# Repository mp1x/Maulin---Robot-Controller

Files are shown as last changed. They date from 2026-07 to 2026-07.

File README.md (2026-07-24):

# Maulin---Robot-Controller
This project is a custom ESP32-based robotics controller designed for dual DC motors, quadrature encoders, an MPU6050 IMU, SSD1306 OLED display, emergency stop system, and battery monitoring. The project includes a full KiCad schematic, PCB layout, Wokwi simulation, and ESP32 firmware.

This project is not a robot itself, however, it is the electronics that power a robot, the complete control system that acts as the robot’s brain. Instead of building wheels or a chassis, this project focuses on designing a universal robotics controller built around the ESP32, capable of driving motors, reading quadrature encoders, processing IMU data, handling emergency stop safety, monitoring battery voltage, and displaying system information on an OLED dashboard. The controller integrates all the core functions real robots rely on internally: motion tracking, speed and distance measurement, drift correction, orientation sensing, and safety logic. This board can be mounted onto any future robot—rovers, line followers, balancing robots, robotic arms, or any system that needs precise motor control and feedback. In short, this project builds the brain, not the body, forming a professional foundation for future robotics development.

## Wokwi Simulation
This project includes a full Wokwi simulation of the ESP32, OLED, IMU, and encoders.

Simulation link: https://wokwi.com/projects/468589263635231745

## Project Files
- /schematic — KiCad schematic + PNG/PDF
- /pcb — PCB layout screenshots + 3D view
- /firmware — ESP32 code
- /wokwi — Simulation files

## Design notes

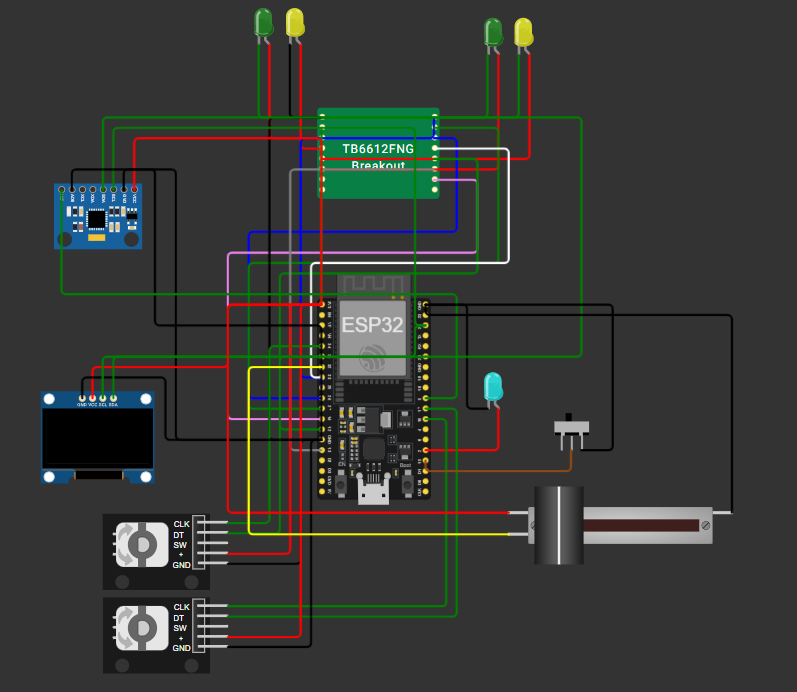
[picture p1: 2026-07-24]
wokwi/wokwi.png

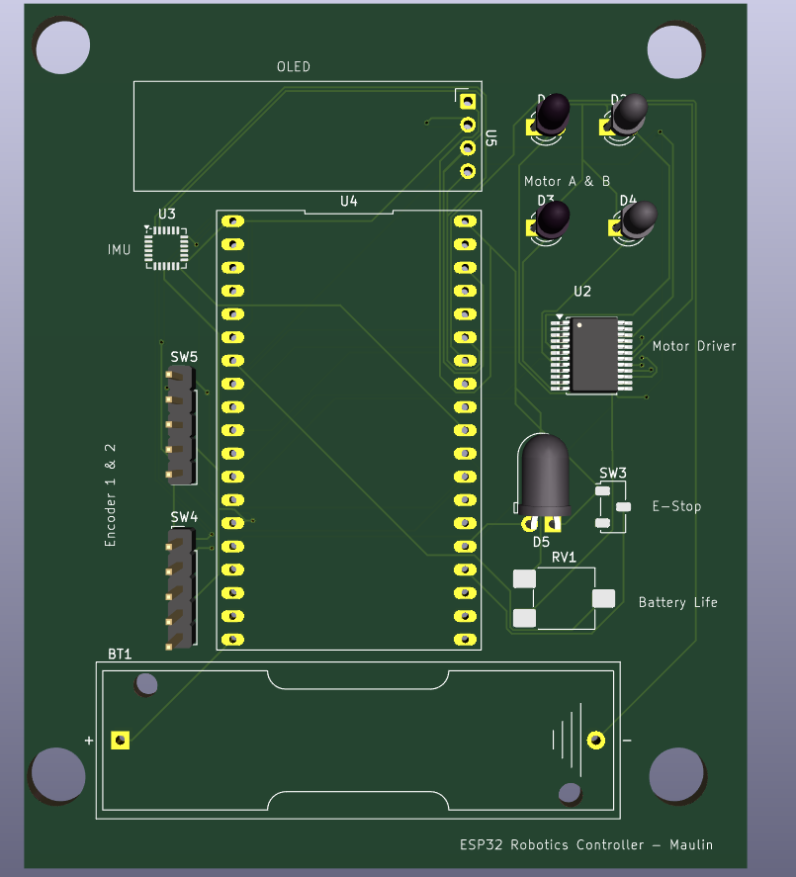
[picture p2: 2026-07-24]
pcb/PCB_roboticscontroller_3D_maulin.png

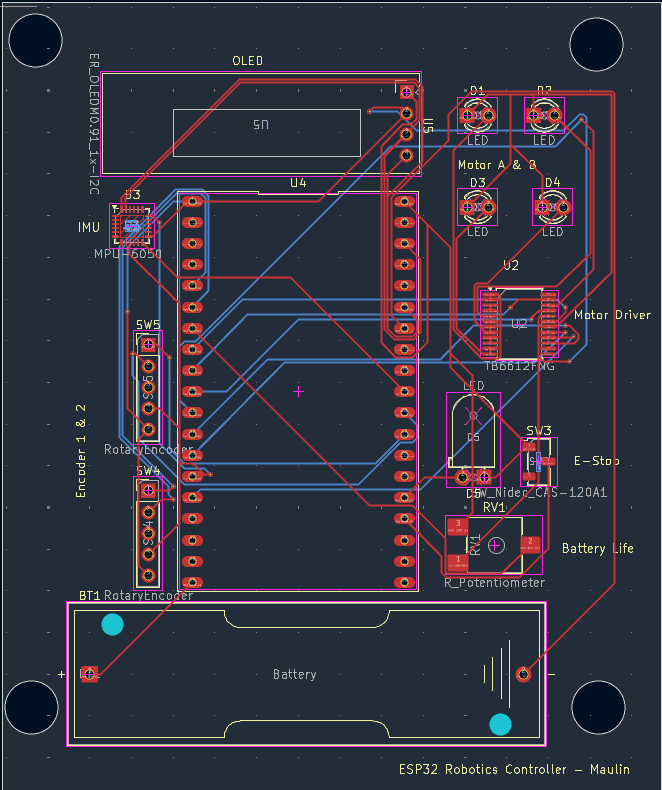
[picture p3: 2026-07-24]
pcb/PCB_roboticscontroller_maulin.png

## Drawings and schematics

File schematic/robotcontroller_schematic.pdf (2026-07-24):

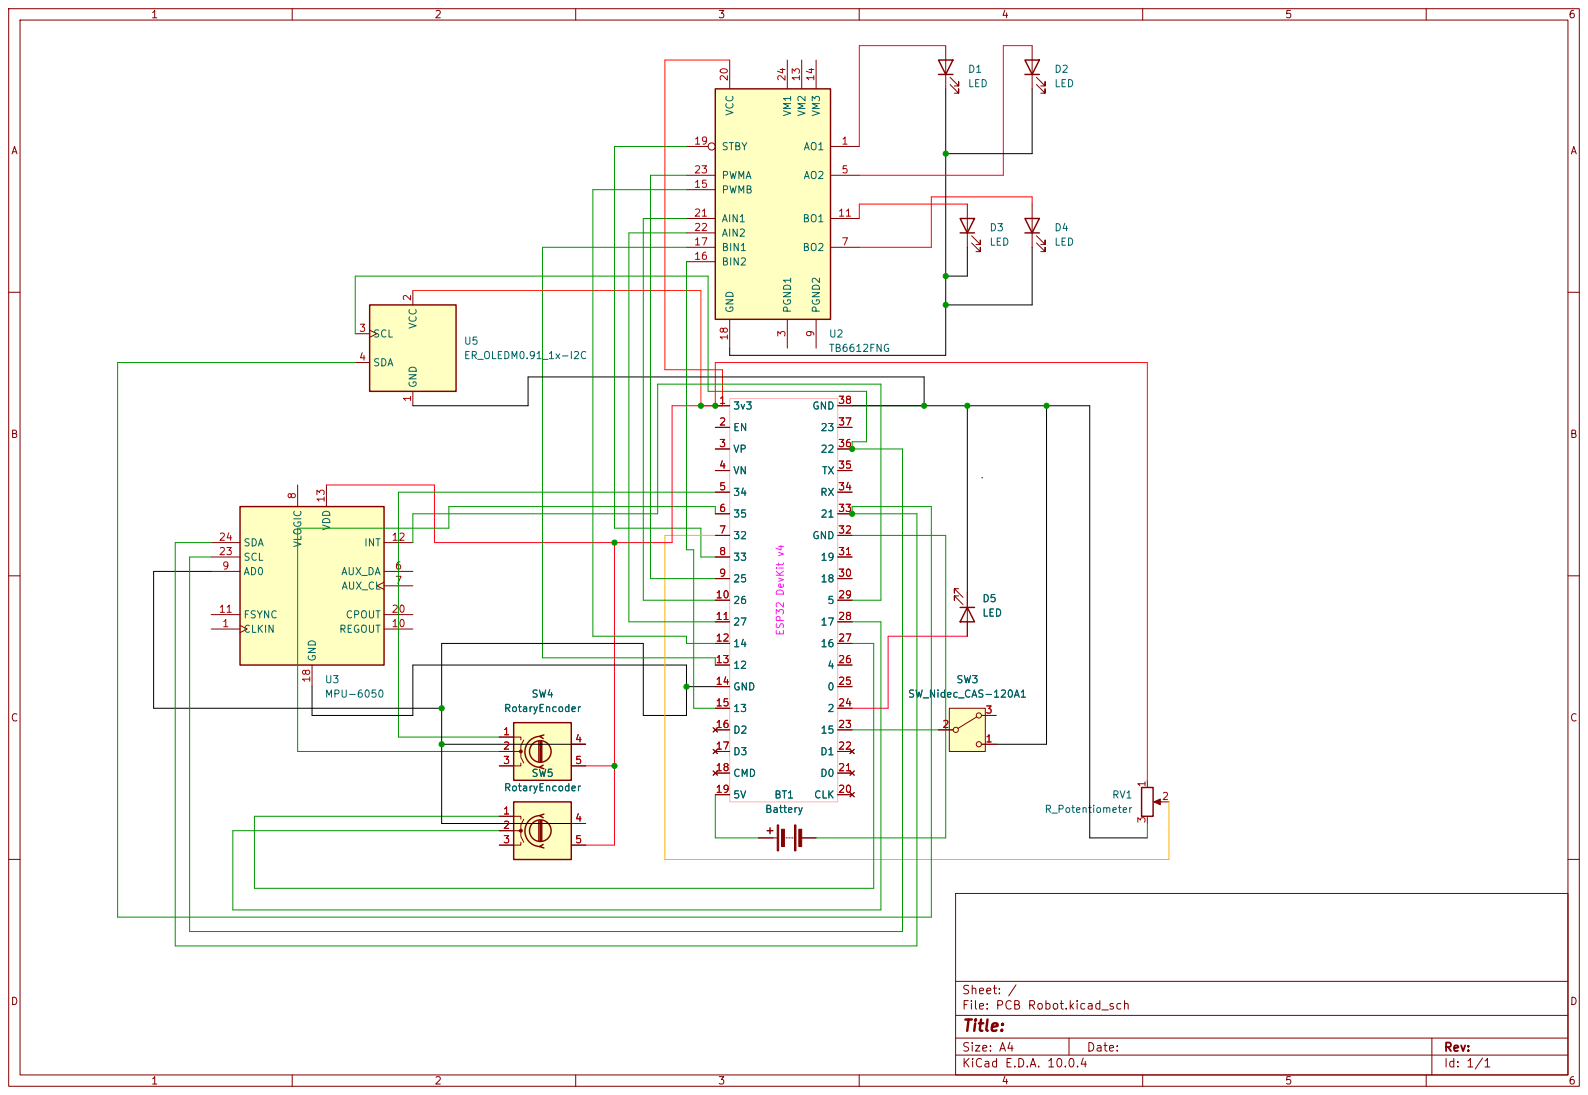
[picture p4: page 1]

19 31 GND 32 19 31 GND 32 33 8 33 8 18 30 18 30 | 29 29

Size: A4 | Rev:
KiCad E.D.A. 10.0.4 | Id: 1/1

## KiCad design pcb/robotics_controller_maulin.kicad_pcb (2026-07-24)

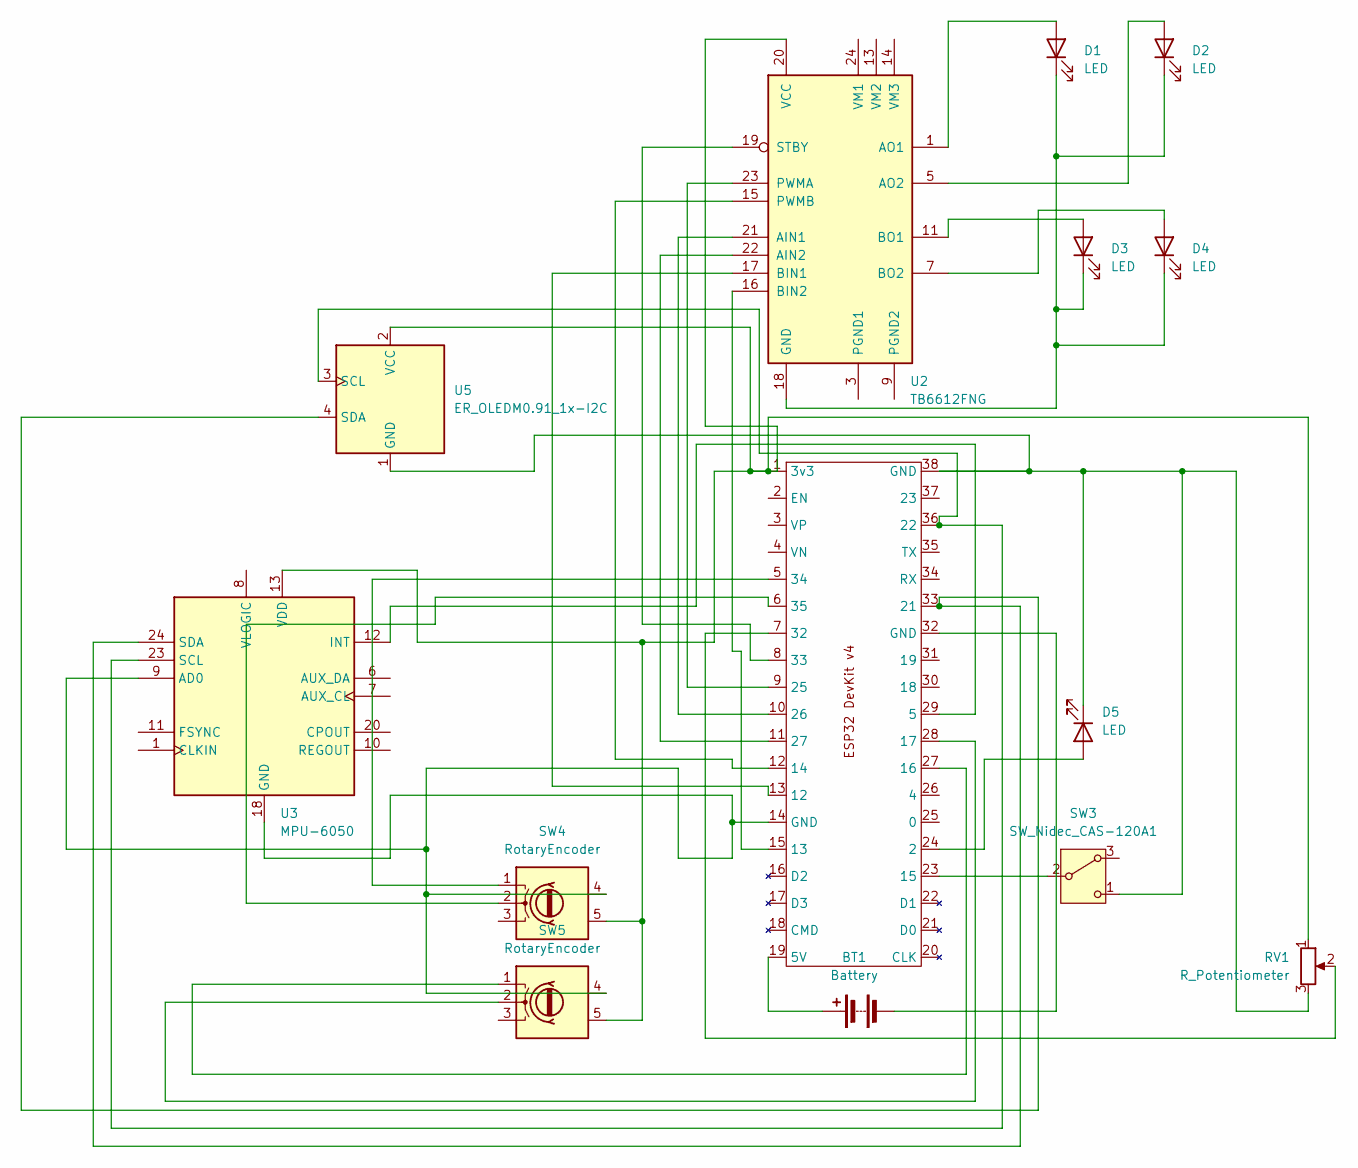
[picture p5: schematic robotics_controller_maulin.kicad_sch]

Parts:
BT1: Battery; BatteryHolder_Keystone_2460_1xAA
D1, D3: LED; LED_D3.0mm_IRBlack
D2, D4: LED; LED_D3.0mm_IRGrey
D5: LED; LED_D5.0mm_Horizontal_O1.27mm_Z3.0mm_IRGrey
RV1: R_Potentiometer; Potentiometer_ACP_CA6-VSMD_Vertical
SW3: SW_Nidec_CAS-120A1; Nidec_Copal_CAS-120A
SW4, SW5: RotaryEncoder; PinHeader_1x05_P2.54mm_Vertical
U2: TB6612FNG; SSOP-24_5.3x8.2mm_P0.65mm
U3: MPU-6050; InvenSense_QFN-24_4x4mm_P0.5mm
U4: ESP32-DevKitC-V4-b
U5: ER_OLEDM0.91_1x-I2C

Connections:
unnamed: BT1.1 (+), U4.19 (5V)
unnamed: BT1.2 (-), U4.32 (GND)
unnamed: D1.2 (A), U2.1 (AO1), U2.2 (AO1)
unnamed: D1.1 (K), D2.1 (K), D3.1 (K), D4.1 (K), U2.18 (GND)
unnamed: D2.2 (A), U2.5 (AO2), U2.6 (AO2)
unnamed: D3.2 (A), U2.11 (BO1), U2.12 (BO1)
unnamed: D4.2 (A), U2.7 (BO2), U2.8 (BO2)
unnamed: D5.2 (A), U4.24 (2)
unnamed: D5.1 (K), RV1.3, SW3.1 (C), U4.38 (GND), U5.1 (GND)
unnamed: SW3.2 (B), U4.23 (15)
unnamed: SW4.1 (CLK), U4.5 (34)
unnamed: SW4.2 (DT), U4.6 (35)
unnamed: SW4.4 (GND), SW5.4 (GND), U3.9 (AD0), U3.18 (GND), U4.14 (GND)
unnamed: RV1.1, SW4.5 (VCC), SW5.5 (VCC), U2.20 (VCC), U3.13 (VDD), U4.1 (3v3), U5.2 (VCC)
unnamed: SW5.1 (CLK), U4.27 (16)
unnamed: SW5.2 (DT), U4.28 (17)
unnamed: U2.21 (AIN1), U4.10 (26)
unnamed: U2.22 (AIN2), U4.11 (27)
unnamed: U2.17 (BIN1), U4.13 (12)
unnamed: U2.16 (BIN2), U4.15 (13)
unnamed: U2.3 (PGND1), U2.4 (PGND1)
unnamed: U2.9 (PGND2), U2.10 (PGND2)
unnamed: U2.23 (PWMA), U4.9 (25)
unnamed: U2.15 (PWMB), U4.12 (14)
unnamed: U2.19 (STBY), U4.8 (33)
unnamed: U3.12 (INT), U4.29 (5)
unnamed: U3.23 (SCL), U4.36 (22), U5.3 (SCL)
unnamed: U3.24 (SDA), U4.33 (21), U5.4 (SDA)
unnamed: RV1.2, U4.7 (32)

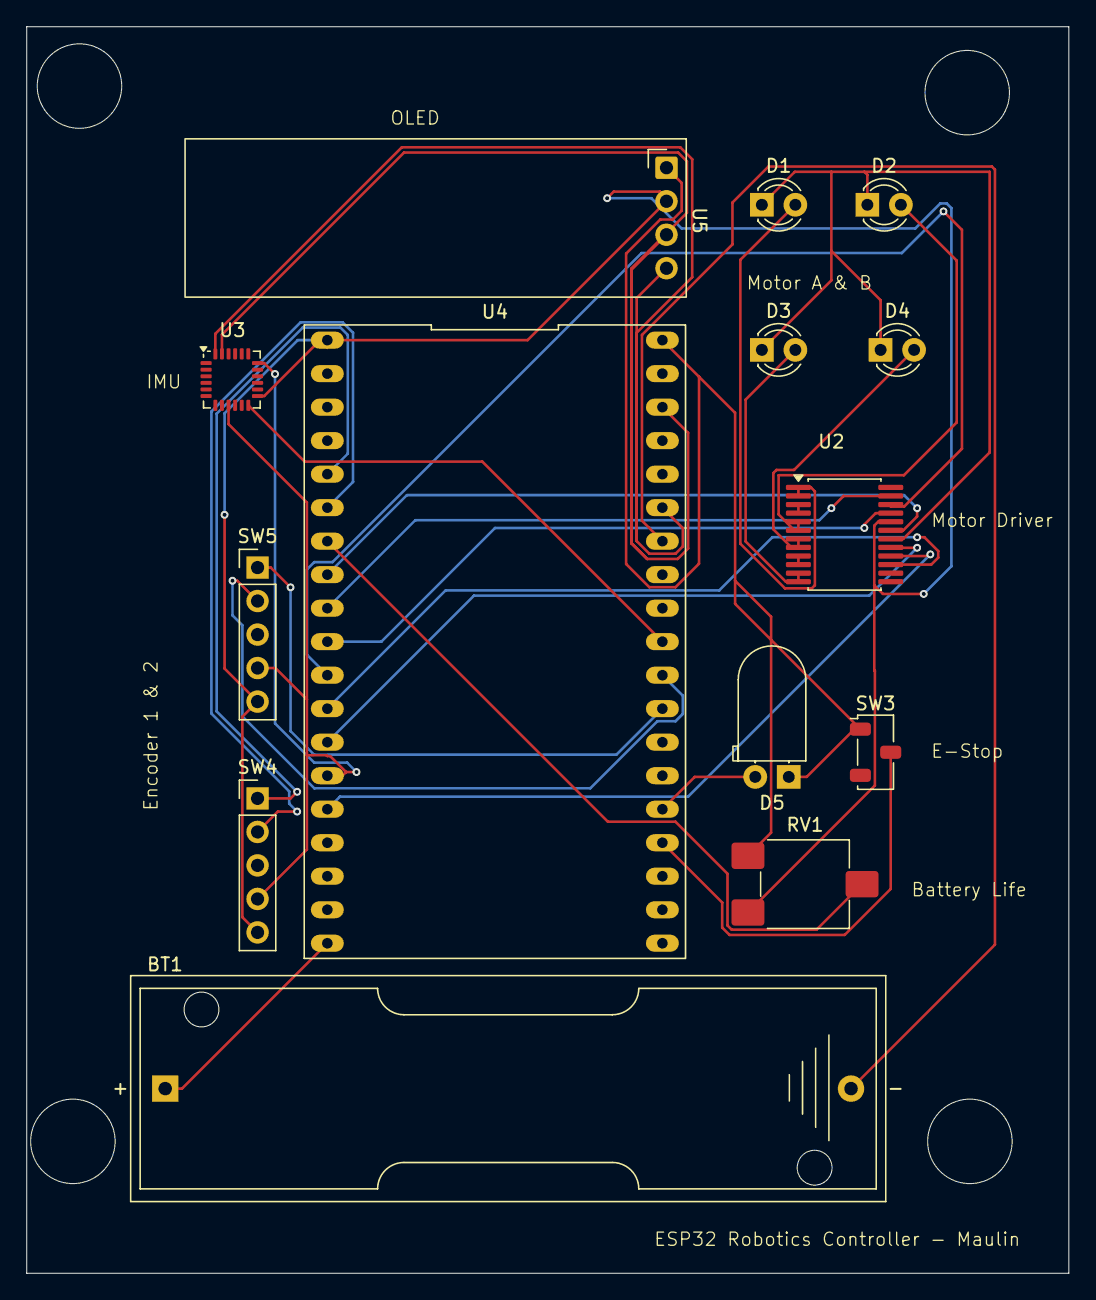
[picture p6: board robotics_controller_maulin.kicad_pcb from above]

Board: 2 copper layers, 79.0 x 94.5 mm, 14 parts (0 on the bottom side), 29 nets.

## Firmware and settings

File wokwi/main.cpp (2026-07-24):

#include <Arduino.h>
#include <Wire.h>
#include <Adafruit_MPU6050.h>
#include <Adafruit_Sensor.h>
#include <Adafruit_GFX.h>
#include <Adafruit_SSD1306.h>

// =========================
// OLED DISPLAY
// =========================
#define SCREEN_WIDTH 128
#define SCREEN_HEIGHT 64
Adafruit_SSD1306 display(SCREEN_WIDTH, SCREEN_HEIGHT, &Wire, -1);

// =========================
// MOTOR DRIVER PINS
// =========================
#define PWMA 25
#define AIN1 26
#define AIN2 27

#define PWMB 14
#define BIN1 12
#define BIN2 13

#define STBY 33

// =========================
// EMERGENCY STOP
// =========================
#define ESTOP_BTN 15
#define ESTOP_LED 2

// =========================
// ENCODERS
// =========================
#define ENC1_CLK 34
#define ENC1_DT  35

#define ENC2_CLK 16
#define ENC2_DT  17

// =========================
// IMU (MPU6050)
// =========================
Adafruit_MPU6050 mpu;
float lastGyroZ = 0;

// =========================
// BATTERY MONITOR (ADC)
// =========================
#define BATTERY_PIN 32
float batteryVoltage = 0;
float batteryPercent = 0;

// =========================
// STATE VARIABLES
// =========================
bool estop_active = false;
bool estop_released_wait = false;
unsigned long estop_release_time = 0;

// =========================
// ENCODER COUNTS
// =========================
volatile long encoderA_count = 0;
volatile long encoderB_count = 0;

// =========================
// ENCODER INTERRUPTS
// =========================
void IRAM_ATTR encoderA_ISR() {
  int clk = digitalRead(ENC1_CLK);
  int dt  = digitalRead(ENC1_DT);
  if (clk == dt) encoderA_count++;
  else encoderA_count--;
}

void IRAM_ATTR encoderB_ISR() {
  int clk = digitalRead(ENC2_CLK);
  int dt  = digitalRead(ENC2_DT);
  if (clk == dt) encoderB_count++;
  else encoderB_count--;
}

// =========================
// DISTANCE CALCULATION
// =========================
float cm_per_step = 1.02;

float getDistanceA() { return encoderA_count * cm_per_step; }
float getDistanceB() { return encoderB_count * cm_per_step; }

// =========================
// SPEED CALCULATION
// =========================
unsigned long lastSpeedTime = 0;
long lastA = 0;
long lastB = 0;

float speedA = 0;
float speedB = 0;

void updateSpeed() {
  unsigned long now = millis();
  if (now - lastSpeedTime >= 1000) {
    speedA = (encoderA_count - lastA) * cm_per_step;
    speedB = (encoderB_count - lastB) * cm_per_step;
    lastA = encoderA_count;
    lastB = encoderB_count;
    lastSpeedTime = now;
  }
}

// =========================
// IMU READ FUNCTION
// =========================
void readIMU() {
  sensors_event_t a, g, temp;
  mpu.getEvent(&a, &g, &temp);
  lastGyroZ = g.gyro.z;
}

// =========================
// BATTERY MONITOR FUNCTION
// =========================
void updateBattery() {
  int raw = analogRead(BATTERY_PIN);      // 0–4095
  float volts = (raw / 4095.0) * 3.3;     // Convert to 0–3.3V
  batteryVoltage = volts;

  batteryPercent = (batteryVoltage / 3.3) * 100.0;
  if (batteryPercent > 100) batteryPercent = 100;
  if (batteryPercent < 0) batteryPercent = 0;
}

// =========================
// SERIAL TELEMETRY (prints once per second)
// =========================
unsigned long lastPrint = 0;
unsigned long lastBatteryPrint = 0;

void printTelemetry() {
  Serial.print("Dist L: ");
  Serial.print(getDistanceA());
  Serial.print("  Dist R: ");
  Serial.println(getDistanceB());

  Serial.print("Speed L: ");
  Serial.print(speedA);
  Serial.print("  Speed R: ");
  Serial.println(speedB);

  Serial.print("Gyro Z: ");
  Serial.println(lastGyroZ);

  Serial.println("----------------------");
}

void printBatteryEvery5Sec() {
  if (millis() - lastBatteryPrint >= 5000) {
    Serial.print("Battery Voltage: ");
    Serial.print(batteryVoltage, 2);
    Serial.print(" V  (");
    Serial.print(batteryPercent, 0);
    Serial.println("%)");
    lastBatteryPrint = millis();
  }
}

// =========================
// OLED DASHBOARD
// =========================
void updateOLED() {
  display.clearDisplay();
  display.setTextSize(1);
  display.setTextColor(SSD1306_WHITE);

  display.setCursor(0, 0);
  display.print("Dist L: ");
  display.print(getDistanceA());

  display.setCursor(0, 10);
  display.print("Dist R: ");
  display.print(getDistanceB());

  display.setCursor(0, 20);
  display.print("Speed L: ");
  display.print(speedA);

  display.setCursor(0, 30);
  display.print("Speed R: ");
  display.print(speedB);

  display.setCursor(0, 40);
  display.print("Gyro Z: ");
  display.print(lastGyroZ);

  display.setCursor(70, 0);
  display.print("Bat:");
  display.print(batteryVoltage, 2);

  display.setCursor(70, 10);
  display.print("Pct:");
  display.print(batteryPercent, 0);
  display.print("%");

  display.setCursor(0, 50);
  if (estop_active) display.print("ESTOP: ACTIVE");
  else display.print("ESTOP: OK");

  display.display();
}

// =========================
// MOTOR FUNCTIONS
// =========================
void motorA_forward(int speed) {
  digitalWrite(AIN1, HIGH);
  digitalWrite(AIN2, LOW);
  analogWrite(PWMA, speed);
}

void motorA_reverse(int speed) {
  digitalWrite(AIN1, LOW);
  digitalWrite(AIN2, HIGH);
  analogWrite(PWMA, speed);
}

void motorA_stop() {
  digitalWrite(AIN1, LOW);
  digitalWrite(AIN2, LOW);
  analogWrite(PWMA, 0);
}

void motorB_forward(int speed) {
  digitalWrite(BIN1, HIGH);
  digitalWrite(BIN2, LOW);
  analogWrite(PWMB, speed);
}

void motorB_reverse(int speed) {
  digitalWrite(BIN1, LOW);
  digitalWrite(BIN2, HIGH);
  analogWrite(PWMB, speed);
}

void motorB_stop() {
  digitalWrite(BIN1, LOW);
  digitalWrite(BIN2, LOW);
  analogWrite(PWMB, 0);
}

void stop_all() {
  motorA_stop();
  motorB_stop();
}

// =========================
// EMERGENCY STOP
// =========================
void checkEmergencyStop() {
  bool pressed = (digitalRead(ESTOP_BTN) == LOW);

  if (pressed && !estop_active) {
    estop_active = true;
    estop_released_wait = false;
    digitalWrite(ESTOP_LED, HIGH);
    stop_all();
    Serial.println("ESTOP ACTIVATED");
  }

  if (!pressed && estop_active) {
    estop_active = false;
    estop_released_wait = true;
    estop_release_time = millis();
    digitalWrite(ESTOP_LED, LOW);
    Serial.println("ESTOP RELEASED - WAITING 5 SEC");
    stop_all();
  }
}

// =========================
// STRAIGHT-LINE CORRECTION
// =========================
void correctStraight(int baseSpeed) {
  int diff = encoderA_count - encoderB_count;
  int correction = diff * 2;
  motorA_forward(baseSpeed - correction);
  motorB_forward(baseSpeed + correction);
}

// =========================
// SETUP
// =========================
void setup() {
  Serial.begin(115200);

  pinMode(PWMA, OUTPUT);
  pinMode(AIN1, OUTPUT);
  pinMode(AIN2, OUTPUT);

  pinMode(PWMB, OUTPUT);
  pinMode(BIN1, OUTPUT);
  pinMode(BIN2, OUTPUT);

  pinMode(STBY, OUTPUT);
  digitalWrite(STBY, HIGH);

  pinMode(ESTOP_BTN, INPUT_PULLUP);
  pinMode(ESTOP_LED, OUTPUT);

  pinMode(ENC1_CLK, INPUT);
  pinMode(ENC1_DT, INPUT);
  pinMode(ENC2_CLK, INPUT);
  pinMode(ENC2_DT, INPUT);

  attachInterrupt(ENC1_CLK, encoderA_ISR, CHANGE);
  attachInterrupt(ENC2_CLK, encoderB_ISR, CHANGE);

  Wire.begin(21, 22);

  if (!mpu.begin()) {
    Serial.println("Failed to find MPU6050!");
    while (1) delay(10);
  }

  mpu.setAccelerometerRange(MPU6050_RANGE_4_G);
  mpu.setGyroRange(MPU6050_RANGE_500_DEG);
  mpu.setFilterBandwidth(MPU6050_BAND_21_HZ);

  pinMode(BATTERY_PIN, INPUT);
  analogReadResolution(12);

  if (!display.begin(SSD1306_SWITCHCAPVCC, 0x3C)) {
    Serial.println("OLED not found!");
    while (true);
  }

  display.clearDisplay();
  display.setTextSize(1);
  display.setTextColor(SSD1306_WHITE);
  display.setCursor(0, 0);
  display.println("Controller Ready");
  display.display();

  Serial.println("Motor Controller + Encoders + IMU + OLED + Battery Ready");
}

// =========================
// LOOP
// =========================
void loop() {

  checkEmergencyStop();
  if (estop_active) { stop_all(); return; }

  if (estop_released_wait) {
    stop_all();
    if (millis() - estop_release_time >= 5000) {
      estop_released_wait = false;
    } else return;
  }

  // FORWARD
  Serial.println("FORWARD");
  correctStraight(180);
  delay(2000);

  updateSpeed();
  readIMU();
  updateBattery();
  printTelemetry();
  printBatteryEvery5Sec();
  updateOLED();

  checkEmergencyStop();
  if (estop_active) return;

  // REVERSE
  Serial.println("REVERSE");
  motorA_reverse(180);
  motorB_reverse(180);
  delay(2000);

  updateSpeed();
  readIMU();
  updateBattery();
  printTelemetry();
  printBatteryEvery5Sec();
  updateOLED();

  checkEmergencyStop();
  if (estop_active) return;

  // STOP
  Serial.println("STOP");
  stop_all();
  delay(1500);

  updateBattery();
  printBatteryEvery5Sec();
  updateOLED();
}

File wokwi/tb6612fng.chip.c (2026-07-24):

// Modified from code found in https://wokwi.com/projects/351764383409373773
// Modified to be digital, not analog, and 
// add pins for a TB6612FNG https://www.pololu.com/product/713

// See also L298N: https://wokwi.com/projects/410302035690579969
// and L298N: https://wokwi.com/projects/386822856593519617
// This progect TB6612FNG https://wokwi.com/projects/410323062531374081

/*
{
  "name": "TB6612FNG",
  "author": "David Forrest",
  "pins": [
    "GND",
    "VCC",
    "AO1",     
    "AO2",
    "BO2",
    "BO1",
    "VMOT",
    "GND",
    "GND",
    "PWMB",
    "BIN2",
    "BIN1",
    "nSTBY",
    "AIN1",
    "AIN2",
    "PWMA"
  ],
  "controls": [
    {
      "id": "Vs",
      "label": "External Voltage (V)",
      "type": "range",
      "min": 0,
      "max": 13.5,
      "step": 0.1
    }
  ]
}
*/

#include "wokwi-api.h"
#include <stdio.h>
#include <stdlib.h>

typedef struct {
  pin_t pin_AO1;
  pin_t pin_AO2;
  pin_t pin_BO1;
  pin_t pin_BO2;
  pin_t pin_AIN1;
  pin_t pin_AIN2;
  pin_t pin_BIN1;
  pin_t pin_BIN2;
  pin_t pin_nSTBY;
  pin_t pin_PWMA;
  pin_t pin_PWMB;
  uint32_t Vs_attr; 
} chip_state_t;



static void chip_pin_change(void *user_data, pin_t pin, uint32_t value);

void chip_init(void) {
  chip_state_t *chip = malloc(sizeof(chip_state_t));

  chip->pin_nSTBY = pin_init("nSTBY",INPUT_PULLDOWN);
  chip->pin_PWMA = pin_init("PWMA",INPUT);
  chip->pin_PWMB = pin_init("PWMB",INPUT);
  chip->pin_AIN1 = pin_init("AIN1",INPUT);
  chip->pin_AIN2 = pin_init("AIN2",INPUT);
  chip->pin_BIN1 = pin_init("BIN1",INPUT);
  chip->pin_BIN2 = pin_init("BIN2",INPUT);
  chip->pin_AO1 = pin_init("AO1",OUTPUT);
  chip->pin_AO2 = pin_init("AO2",OUTPUT);
  chip->pin_BO1 = pin_init("BO1",OUTPUT);
  chip->pin_BO2 = pin_init("BO2",OUTPUT);
  chip->Vs_attr = attr_init_float("Vs", 12.0);
  const pin_watch_config_t watch_config = {
    .edge = BOTH,
    .pin_change = chip_pin_change,
    .user_data = chip
  };
  pin_watch(chip->pin_PWMA, &watch_config);
  pin_watch(chip->pin_PWMB, &watch_config);
  pin_watch(chip->pin_AIN1, &watch_config);
  pin_watch(chip->pin_AIN2, &watch_config);
  pin_watch(chip->pin_BIN1, &watch_config);
  pin_watch(chip->pin_BIN2, &watch_config);
  pin_watch(chip->pin_nSTBY, &watch_config);
}

void chip_pin_change(void *user_data, pin_t pin, uint32_t value) {
  chip_state_t *chip = (chip_state_t*)user_data;
  int PWMA = pin_read(chip->pin_PWMA);
  int PWMB = pin_read(chip->pin_PWMB);
  int AIN1 = pin_read(chip->pin_AIN1);
  int AIN2 = pin_read(chip->pin_AIN2);
  int BIN1 = pin_read(chip->pin_BIN1);
  int BIN2 = pin_read(chip->pin_BIN2);
  int nSTBY = pin_read(chip->pin_nSTBY);
  float Vs = attr_read_float(chip->Vs_attr);
  
  // motor A control
  if (AIN1 && nSTBY) 
   // pin_dac_write(chip->pin_out1,PWMA*Vs);
    pin_write(chip->pin_AO1,PWMA);
  else
    pin_write(chip->pin_AO1,0);
  if (AIN2 && nSTBY)
    pin_write(chip->pin_AO2,PWMA);
  else
    pin_write(chip->pin_AO2,0);
  //motor B control
  if (BIN1 && nSTBY) 
    pin_write(chip->pin_BO1,PWMB);
  else
    pin_write(chip->pin_BO1,0);
  if (BIN2 && nSTBY)
    pin_write(chip->pin_BO2,PWMB);
  else
    pin_write(chip->pin_BO2,0);
}

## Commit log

2026-07-24 Add schematic folder
2026-07-24 add pcb folder
